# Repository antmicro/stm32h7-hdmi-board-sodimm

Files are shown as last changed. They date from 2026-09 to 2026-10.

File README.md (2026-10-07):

# SODIMM for STM32H7 HDMI Board

Copyright (c) 2026 [Antmicro](https://www.antmicro.com)

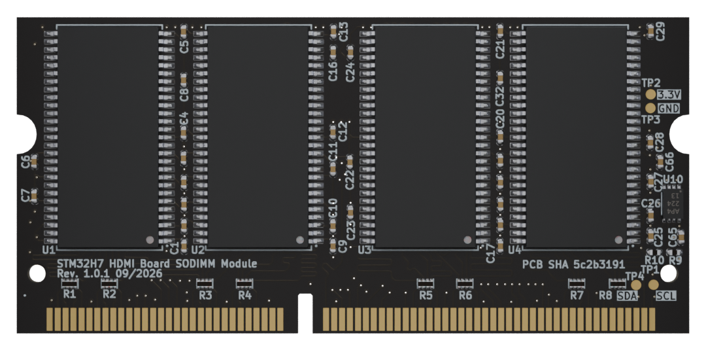
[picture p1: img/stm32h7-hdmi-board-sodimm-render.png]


## Overview

This project includes PCB design files for a custom SDRAM memory module in SO-DIMM form factor. 
This module is compatible with [STM32H7 HDMI Board](https://github.com/antmicro/stm32h7-hdmi-board) developed by Antmicro. 
It provides 512 MB of SDRAM memory supporting a maximum memory clock frequency of 200 MHz, and exposes a 32-bit data bus for full compatibility with the STM32H747 FMC (Flexible Memory Controller) used in the STM32H7 HDMI Board design. 
The board design follows the JEDEC 144-pin SODIMM pin assignment with only half of the data bus implemented (32 bits).
It also features an EEPROM memory chip for Serial Presence Detect.
The board dimensions comply with the MO-190-C SODIMM Mechanical Specifications.
The PCB design files were prepared in KiCad 10.x.

## Key features

* 512 MB of SDRAM memory
* 144 Pin SODIMM PCB edge connector
* 2Rx8 (32 data bus) memory organization
* 8 x ISSI IS42S86400F-7TL SDRAM devices with a maximum clock frequency of 200MHz
* JEDEC 144-pin SODIMM pin-assignment with only half of the data bus implemented (DQ[0..31])
* Board outline compliant with the MO-190-C SODIMM Mechanical Specifications
* Compatible with STM32H747 FMC
* 67.6 x 31.75 mm (2.66 x 1.25 inch) PCB outline

## Project structure

The main directory contains KiCad PCB project files, the LICENSE, and this README, and the img directory contains graphics for this README.

## Licensing

This project is published under the [Apache-2.0](LICENSE) license.

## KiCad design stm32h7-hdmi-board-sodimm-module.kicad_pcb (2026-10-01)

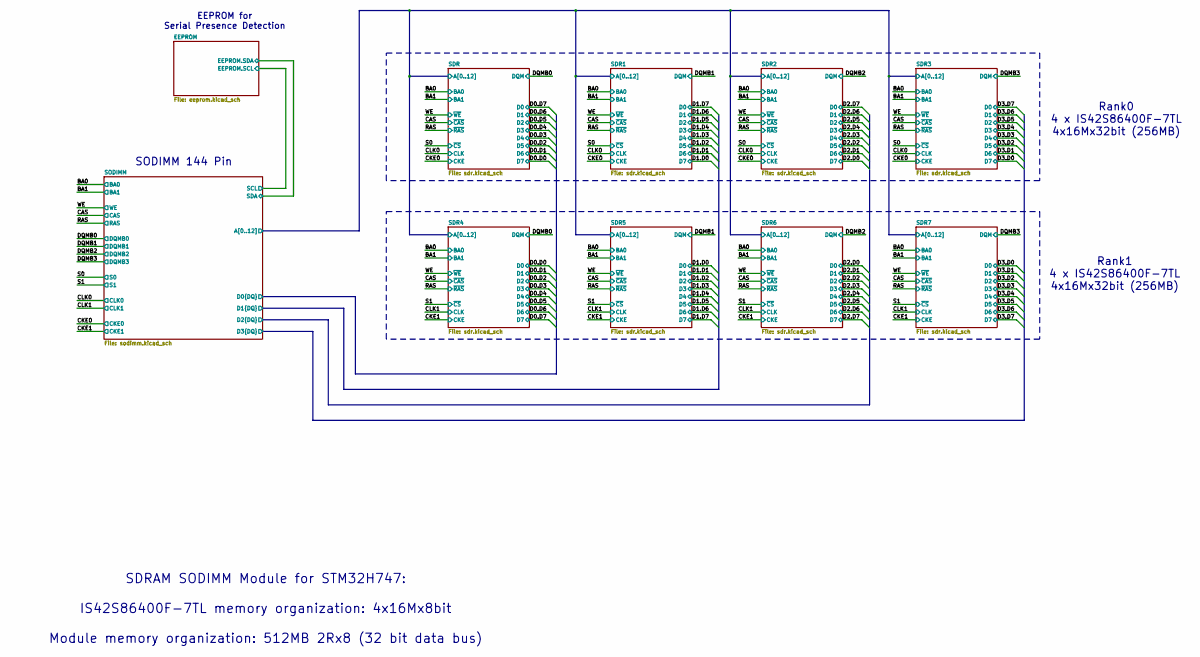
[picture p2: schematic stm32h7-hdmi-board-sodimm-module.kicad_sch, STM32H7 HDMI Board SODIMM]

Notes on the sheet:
Rank0 4 x IS42S86400F-7TL 4x16Mx32bit (256MB)
Rank1 4 x IS42S86400F-7TL 4x16Mx32bit (256MB)
SDRAM SODIMM Module for STM32H747: IS42S86400F-7TL memory organization: 4x16Mx8bit Module memory organization: 512MB 2Rx8 (32 bit data bus)
SODIMM 144 Pin
EEPROM for Serial Presence Detection

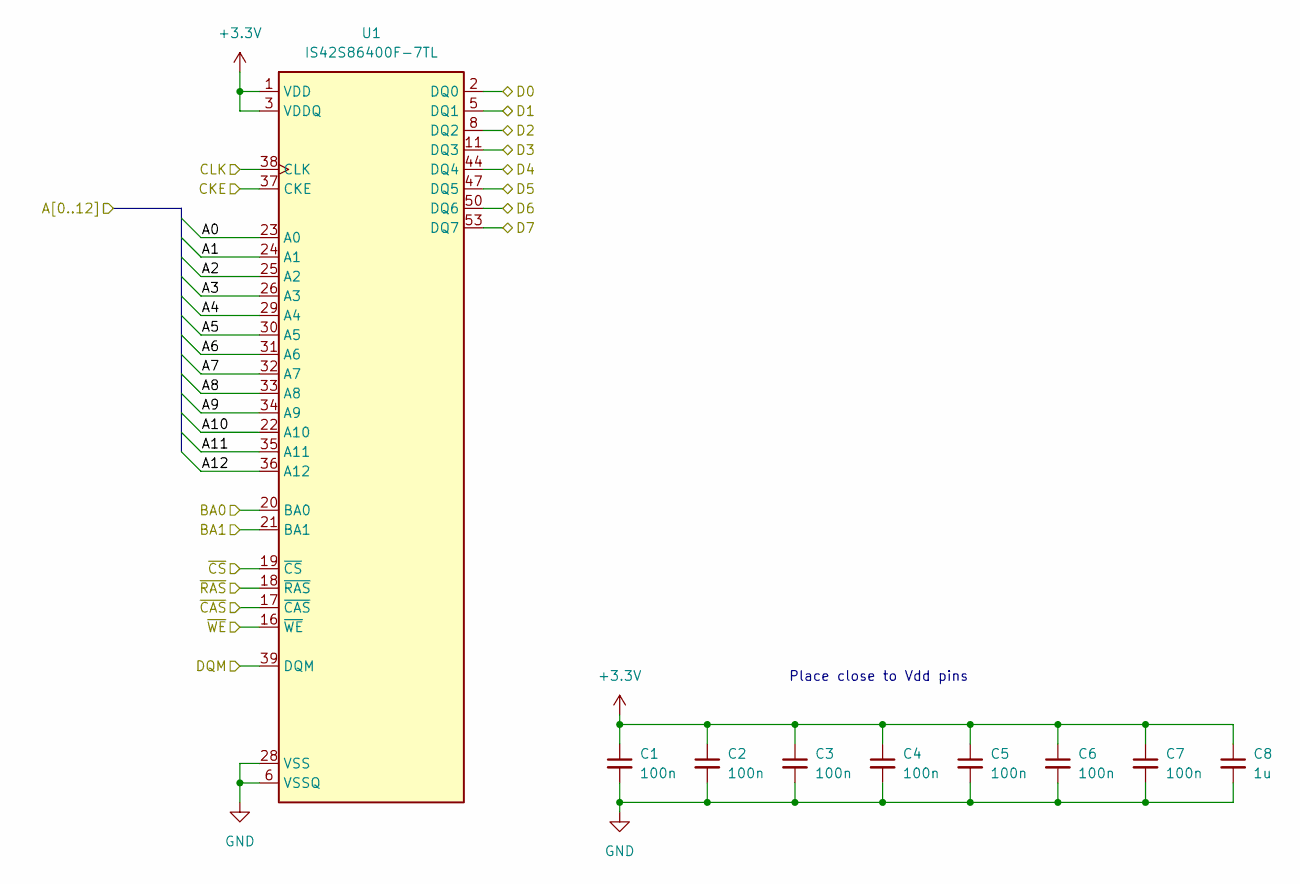
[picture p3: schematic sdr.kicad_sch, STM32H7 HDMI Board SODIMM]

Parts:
C1, C2, C3, C4, C5, C6, C7: C_100n_0402; C_0402_1005Metric; Voltage 50V; MPN GRM155R61H104KE14D
C8: C_1u_0402; C_0402_1005Metric; MPN C1005X6S1A105K050BC
U1: IS42S86400F-7TL; TSOP-II-54_22.2x10.16mm_P0.8mm; MPN IS42S86400F-7TL

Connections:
+3.3V: C1.1, C2.1, C3.1, C4.1, C5.1, C6.1, C7.1, C8.1, U1.1 (VDD), U1.3 (VDDQ), U1.9 (VDDQ), U1.14 (VDD), U1.27 (VDD), U1.43 (VDDQ), U1.49 (VDDQ); also elsewhere on the board
/BA0: U1.20 (BA0); also elsewhere on the board
/BA1: U1.21 (BA1); also elsewhere on the board
/CAS: U1.17 (~CAS); also elsewhere on the board
/CKE0: U1.37 (CKE); also elsewhere on the board
/CLK0: U1.38 (CLK); also elsewhere on the board
/DQMB0: U1.39 (DQM); also elsewhere on the board
/RAS: U1.18 (~RAS); also elsewhere on the board
/S0: U1.19 (~CS); also elsewhere on the board
/SDR/A0: U1.23 (A0); also elsewhere on the board
/SDR/A1: U1.24 (A1); also elsewhere on the board
/SDR/A2: U1.25 (A2); also elsewhere on the board
/SDR/A3: U1.26 (A3); also elsewhere on the board
/SDR/A4: U1.29 (A4); also elsewhere on the board
/SDR/A5: U1.30 (A5); also elsewhere on the board
/SDR/A6: U1.31 (A6); also elsewhere on the board
/SDR/A7: U1.32 (A7); also elsewhere on the board
/SDR/A8: U1.33 (A8); also elsewhere on the board
/SDR/A9: U1.34 (A9); also elsewhere on the board
/SDR/A10: U1.22 (A10); also elsewhere on the board
/SDR/A11: U1.35 (A11); also elsewhere on the board
/SDR/A12: U1.36 (A12); also elsewhere on the board
/SODIMM/D0.D0: U1.53 (DQ7); also elsewhere on the board
/SODIMM/D0.D1: U1.50 (DQ6); also elsewhere on the board
/SODIMM/D0.D2: U1.47 (DQ5); also elsewhere on the board
/SODIMM/D0.D3: U1.44 (DQ4); also elsewhere on the board
/SODIMM/D0.D4: U1.11 (DQ3); also elsewhere on the board
/SODIMM/D0.D5: U1.8 (DQ2); also elsewhere on the board
/SODIMM/D0.D6: U1.5 (DQ1); also elsewhere on the board
/SODIMM/D0.D7: U1.2 (DQ0); also elsewhere on the board
/WE: U1.16 (~WE); also elsewhere on the board
GND: C1.2, C2.2, C3.2, C4.2, C5.2, C6.2, C7.2, C8.2, U1.6 (VSSQ), U1.12 (VSSQ), U1.28 (VSS), U1.41 (VSS), U1.46 (VSSQ), U1.52 (VSSQ), U1.54 (VSS); also elsewhere on the board

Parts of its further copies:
C9, C10, C11, C12, C13, C14, C15, C17, C18, C19, C20, C21, C22, C23, C25, C26, C27, C28, C29, C30, C31, C33, C34, C35, C36, C37, C38, C39, C41, C42, C43, C44, C45, C46, C47, C49, C50, C51, C52, C53, C54, C55, C57, C58, C59, C60, C61, C62, C63: C_100n_0402; C_0402_1005Metric; Voltage 50V; MPN GRM155R61H104KE14D
C16, C24, C32, C40, C48, C56, C64: C_1u_0402; C_0402_1005Metric; MPN C1005X6S1A105K050BC
U2, U3, U4, U5, U6, U7, U8: IS42S86400F-7TL; TSOP-II-54_22.2x10.16mm_P0.8mm; MPN IS42S86400F-7TL

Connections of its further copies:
+3.3V: C9.1, C10.1, C11.1, C12.1, C13.1, C14.1, C15.1, C16.1, C17.1, C18.1, C19.1, C20.1, C21.1, C22.1, C23.1, C24.1, C25.1, C26.1, C27.1, C28.1, C29.1, C30.1, C31.1, C32.1, C33.1, C34.1, C35.1, C36.1, C37.1, C38.1, C39.1, C40.1, C41.1, C42.1, C43.1, C44.1, C45.1, C46.1, C47.1, C48.1, C49.1, C50.1, C51.1, C52.1, C53.1, C54.1, C55.1, C56.1, C57.1, C58.1, C59.1, C60.1, C61.1, C62.1, C63.1, C64.1, U2.1 (VDD), U2.3 (VDDQ), U2.9 (VDDQ), U2.14 (VDD), U2.27 (VDD), U2.43 (VDDQ), U2.49 (VDDQ), U3.1 (VDD), U3.3 (VDDQ), U3.9 (VDDQ), U3.14 (VDD), U3.27 (VDD), U3.43 (VDDQ), U3.49 (VDDQ), U4.1 (VDD), U4.3 (VDDQ), U4.9 (VDDQ), U4.14 (VDD), U4.27 (VDD), U4.43 (VDDQ), U4.49 (VDDQ), U5.1 (VDD), U5.3 (VDDQ), U5.9 (VDDQ), U5.14 (VDD), U5.27 (VDD), U5.43 (VDDQ), U5.49 (VDDQ), U6.1 (VDD), U6.3 (VDDQ), U6.9 (VDDQ), U6.14 (VDD), U6.27 (VDD), U6.43 (VDDQ), U6.49 (VDDQ), U7.1 (VDD), U7.3 (VDDQ), U7.9 (VDDQ), U7.14 (VDD), U7.27 (VDD), U7.43 (VDDQ), U7.49 (VDDQ), U8.1 (VDD), U8.3 (VDDQ), U8.9 (VDDQ), U8.14 (VDD), U8.27 (VDD), U8.43 (VDDQ), U8.49 (VDDQ); also elsewhere on the board
/BA0: U2.20 (BA0), U3.20 (BA0), U4.20 (BA0), U5.20 (BA0), U6.20 (BA0), U7.20 (BA0), U8.20 (BA0); also elsewhere on the board
/BA1: U2.21 (BA1), U3.21 (BA1), U4.21 (BA1), U5.21 (BA1), U6.21 (BA1), U7.21 (BA1), U8.21 (BA1); also elsewhere on the board
/CAS: U2.17 (~CAS), U3.17 (~CAS), U4.17 (~CAS), U5.17 (~CAS), U6.17 (~CAS), U7.17 (~CAS), U8.17 (~CAS); also elsewhere on the board
/CKE0: U2.37 (CKE), U3.37 (CKE), U4.37 (CKE); also elsewhere on the board
/CKE1: U5.37 (CKE), U6.37 (CKE), U7.37 (CKE), U8.37 (CKE); also elsewhere on the board
/CLK0: U2.38 (CLK), U3.38 (CLK), U4.38 (CLK); also elsewhere on the board
/CLK1: U5.38 (CLK), U6.38 (CLK), U7.38 (CLK), U8.38 (CLK); also elsewhere on the board
/DQMB0: U5.39 (DQM); also elsewhere on the board
/DQMB1: U2.39 (DQM), U6.39 (DQM); also elsewhere on the board
/DQMB2: U3.39 (DQM), U7.39 (DQM); also elsewhere on the board
/DQMB3: U4.39 (DQM), U8.39 (DQM); also elsewhere on the board
/RAS: U2.18 (~RAS), U3.18 (~RAS), U4.18 (~RAS), U5.18 (~RAS), U6.18 (~RAS), U7.18 (~RAS), U8.18 (~RAS); also elsewhere on the board
/S0: U2.19 (~CS), U3.19 (~CS), U4.19 (~CS); also elsewhere on the board
/S1: U5.19 (~CS), U6.19 (~CS), U7.19 (~CS), U8.19 (~CS); also elsewhere on the board
/SDR/A0: U2.23 (A0), U3.23 (A0), U4.23 (A0), U5.23 (A0), U6.23 (A0), U7.23 (A0), U8.23 (A0); also elsewhere on the board
/SDR/A1: U2.24 (A1), U3.24 (A1), U4.24 (A1), U5.24 (A1), U6.24 (A1), U7.24 (A1), U8.24 (A1); also elsewhere on the board
/SDR/A2: U2.25 (A2), U3.25 (A2), U4.25 (A2), U5.25 (A2), U6.25 (A2), U7.25 (A2), U8.25 (A2); also elsewhere on the board
/SDR/A3: U2.26 (A3), U3.26 (A3), U4.26 (A3), U5.26 (A3), U6.26 (A3), U7.26 (A3), U8.26 (A3); also elsewhere on the board
/SDR/A4: U2.29 (A4), U3.29 (A4), U4.29 (A4), U5.29 (A4), U6.29 (A4), U7.29 (A4), U8.29 (A4); also elsewhere on the board
/SDR/A5: U2.30 (A5), U3.30 (A5), U4.30 (A5), U5.30 (A5), U6.30 (A5), U7.30 (A5), U8.30 (A5); also elsewhere on the board
/SDR/A6: U2.31 (A6), U3.31 (A6), U4.31 (A6), U5.31 (A6), U6.31 (A6), U7.31 (A6), U8.31 (A6); also elsewhere on the board
/SDR/A7: U2.32 (A7), U3.32 (A7), U4.32 (A7), U5.32 (A7), U6.32 (A7), U7.32 (A7), U8.32 (A7); also elsewhere on the board
/SDR/A8: U2.33 (A8), U3.33 (A8), U4.33 (A8), U5.33 (A8), U6.33 (A8), U7.33 (A8), U8.33 (A8); also elsewhere on the board
/SDR/A9: U2.34 (A9), U3.34 (A9), U4.34 (A9), U5.34 (A9), U6.34 (A9), U7.34 (A9), U8.34 (A9); also elsewhere on the board
/SDR/A10: U2.22 (A10), U3.22 (A10), U4.22 (A10), U5.22 (A10), U6.22 (A10), U7.22 (A10), U8.22 (A10); also elsewhere on the board
/SDR/A11: U2.35 (A11), U3.35 (A11), U4.35 (A11), U5.35 (A11), U6.35 (A11), U7.35 (A11), U8.35 (A11); also elsewhere on the board
/SDR/A12: U2.36 (A12), U3.36 (A12), U4.36 (A12), U5.36 (A12), U6.36 (A12), U7.36 (A12), U8.36 (A12); also elsewhere on the board
/SODIMM/D0.D0: U5.2 (DQ0); also elsewhere on the board
/SODIMM/D0.D1: U5.5 (DQ1); also elsewhere on the board
/SODIMM/D0.D2: U5.8 (DQ2); also elsewhere on the board
/SODIMM/D0.D3: U5.11 (DQ3); also elsewhere on the board
/SODIMM/D0.D4: U5.44 (DQ4); also elsewhere on the board
/SODIMM/D0.D5: U5.47 (DQ5); also elsewhere on the board
/SODIMM/D0.D6: U5.50 (DQ6); also elsewhere on the board
/SODIMM/D0.D7: U5.53 (DQ7); also elsewhere on the board
/SODIMM/D1.D0: U2.53 (DQ7), U6.2 (DQ0); also elsewhere on the board
/SODIMM/D1.D1: U2.50 (DQ6), U6.5 (DQ1); also elsewhere on the board
/SODIMM/D1.D2: U2.47 (DQ5), U6.8 (DQ2); also elsewhere on the board
/SODIMM/D1.D3: U2.44 (DQ4), U6.11 (DQ3); also elsewhere on the board
/SODIMM/D1.D4: U2.11 (DQ3), U6.44 (DQ4); also elsewhere on the board
/SODIMM/D1.D5: U2.8 (DQ2), U6.47 (DQ5); also elsewhere on the board
/SODIMM/D1.D6: U2.5 (DQ1), U6.50 (DQ6); also elsewhere on the board
/SODIMM/D1.D7: U2.2 (DQ0), U6.53 (DQ7); also elsewhere on the board
/SODIMM/D2.D0: U3.53 (DQ7), U7.2 (DQ0); also elsewhere on the board
/SODIMM/D2.D1: U3.50 (DQ6), U7.5 (DQ1); also elsewhere on the board
/SODIMM/D2.D2: U3.47 (DQ5), U7.8 (DQ2); also elsewhere on the board
/SODIMM/D2.D3: U3.44 (DQ4), U7.11 (DQ3); also elsewhere on the board
/SODIMM/D2.D4: U3.11 (DQ3), U7.44 (DQ4); also elsewhere on the board
/SODIMM/D2.D5: U3.8 (DQ2), U7.47 (DQ5); also elsewhere on the board
/SODIMM/D2.D6: U3.5 (DQ1), U7.50 (DQ6); also elsewhere on the board
/SODIMM/D2.D7: U3.2 (DQ0), U7.53 (DQ7); also elsewhere on the board
/SODIMM/D3.D0: U4.53 (DQ7), U8.2 (DQ0); also elsewhere on the board
/SODIMM/D3.D1: U4.50 (DQ6), U8.5 (DQ1); also elsewhere on the board
/SODIMM/D3.D2: U4.47 (DQ5), U8.8 (DQ2); also elsewhere on the board
/SODIMM/D3.D3: U4.44 (DQ4), U8.11 (DQ3); also elsewhere on the board
/SODIMM/D3.D4: U4.11 (DQ3), U8.44 (DQ4); also elsewhere on the board
/SODIMM/D3.D5: U4.8 (DQ2), U8.47 (DQ5); also elsewhere on the board
/SODIMM/D3.D6: U4.5 (DQ1), U8.50 (DQ6); also elsewhere on the board
/SODIMM/D3.D7: U4.2 (DQ0), U8.53 (DQ7); also elsewhere on the board
/WE: U2.16 (~WE), U3.16 (~WE), U4.16 (~WE), U5.16 (~WE), U6.16 (~WE), U7.16 (~WE), U8.16 (~WE); also elsewhere on the board
GND: C9.2, C10.2, C11.2, C12.2, C13.2, C14.2, C15.2, C16.2, C17.2, C18.2, C19.2, C20.2, C21.2, C22.2, C23.2, C24.2, C25.2, C26.2, C27.2, C28.2, C29.2, C30.2, C31.2, C32.2, C33.2, C34.2, C35.2, C36.2, C37.2, C38.2, C39.2, C40.2, C41.2, C42.2, C43.2, C44.2, C45.2, C46.2, C47.2, C48.2, C49.2, C50.2, C51.2, C52.2, C53.2, C54.2, C55.2, C56.2, C57.2, C58.2, C59.2, C60.2, C61.2, C62.2, C63.2, C64.2, U2.6 (VSSQ), U2.12 (VSSQ), U2.28 (VSS), U2.41 (VSS), U2.46 (VSSQ), U2.52 (VSSQ), U2.54 (VSS), U3.6 (VSSQ), U3.12 (VSSQ), U3.28 (VSS), U3.41 (VSS), U3.46 (VSSQ), U3.52 (VSSQ), U3.54 (VSS), U4.6 (VSSQ), U4.12 (VSSQ), U4.28 (VSS), U4.41 (VSS), U4.46 (VSSQ), U4.52 (VSSQ), U4.54 (VSS), U5.6 (VSSQ), U5.12 (VSSQ), U5.28 (VSS), U5.41 (VSS), U5.46 (VSSQ), U5.52 (VSSQ), U5.54 (VSS), U6.6 (VSSQ), U6.12 (VSSQ), U6.28 (VSS), U6.41 (VSS), U6.46 (VSSQ), U6.52 (VSSQ), U6.54 (VSS), U7.6 (VSSQ), U7.12 (VSSQ), U7.28 (VSS), U7.41 (VSS), U7.46 (VSSQ), U7.52 (VSSQ), U7.54 (VSS), U8.6 (VSSQ), U8.12 (VSSQ), U8.28 (VSS), U8.41 (VSS), U8.46 (VSSQ), U8.52 (VSSQ), U8.54 (VSS); also elsewhere on the board

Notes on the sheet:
Place close to Vdd pins

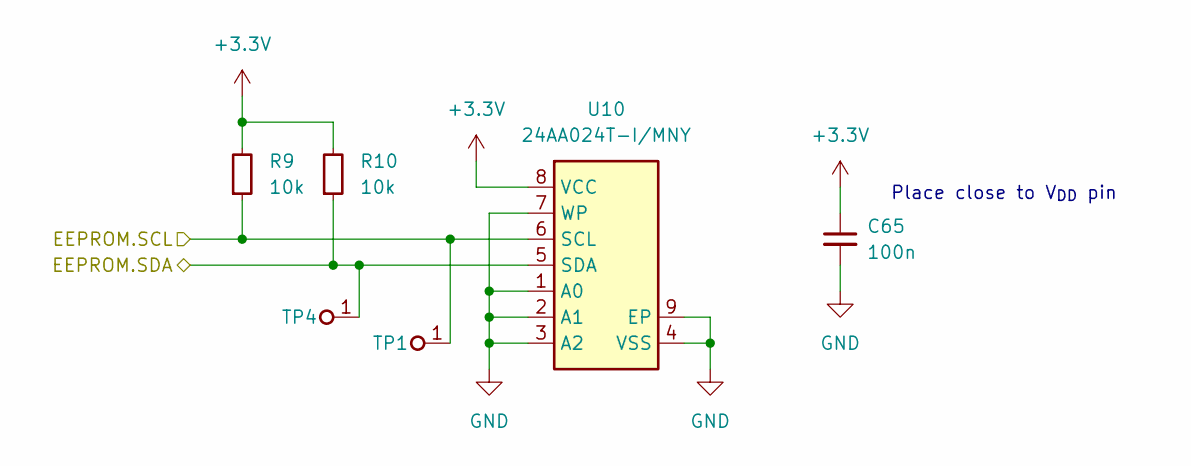
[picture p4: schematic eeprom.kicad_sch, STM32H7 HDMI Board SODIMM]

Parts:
C65: C_100n_0402; C_0402_1005Metric; Voltage 50V; MPN GRM155R61H104KE14D
R9, R10: R_10k_0402; R_0402_1005Metric; Tolerance 1%; MPN CR0402-FX-1002GLF
TP1, TP4: TP_1mm_SMD; TP_SMD_1mm
U10: 24AA024_TDFN; TDFN-8-1EP_2x3x0.8mm_P0.5mm_EP1.3x1.4mm; MPN 24AA024T-I/MNY

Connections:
+3.3V: C65.1, R9.2, R10.2, U10.8 (VCC); also elsewhere on the board
/EEPROM/EEPROM.SCL: R9.1, TP1.1 (1_1), U10.6 (SCL); also elsewhere on the board
/EEPROM/EEPROM.SDA: R10.1, TP4.1 (1_1), U10.5 (SDA); also elsewhere on the board
GND: C65.2, U10.1 (A0), U10.2 (A1), U10.3 (A2), U10.4 (VSS), U10.7 (WP), U10.9 (EP); also elsewhere on the board

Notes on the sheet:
Place close to V_{DD} pin

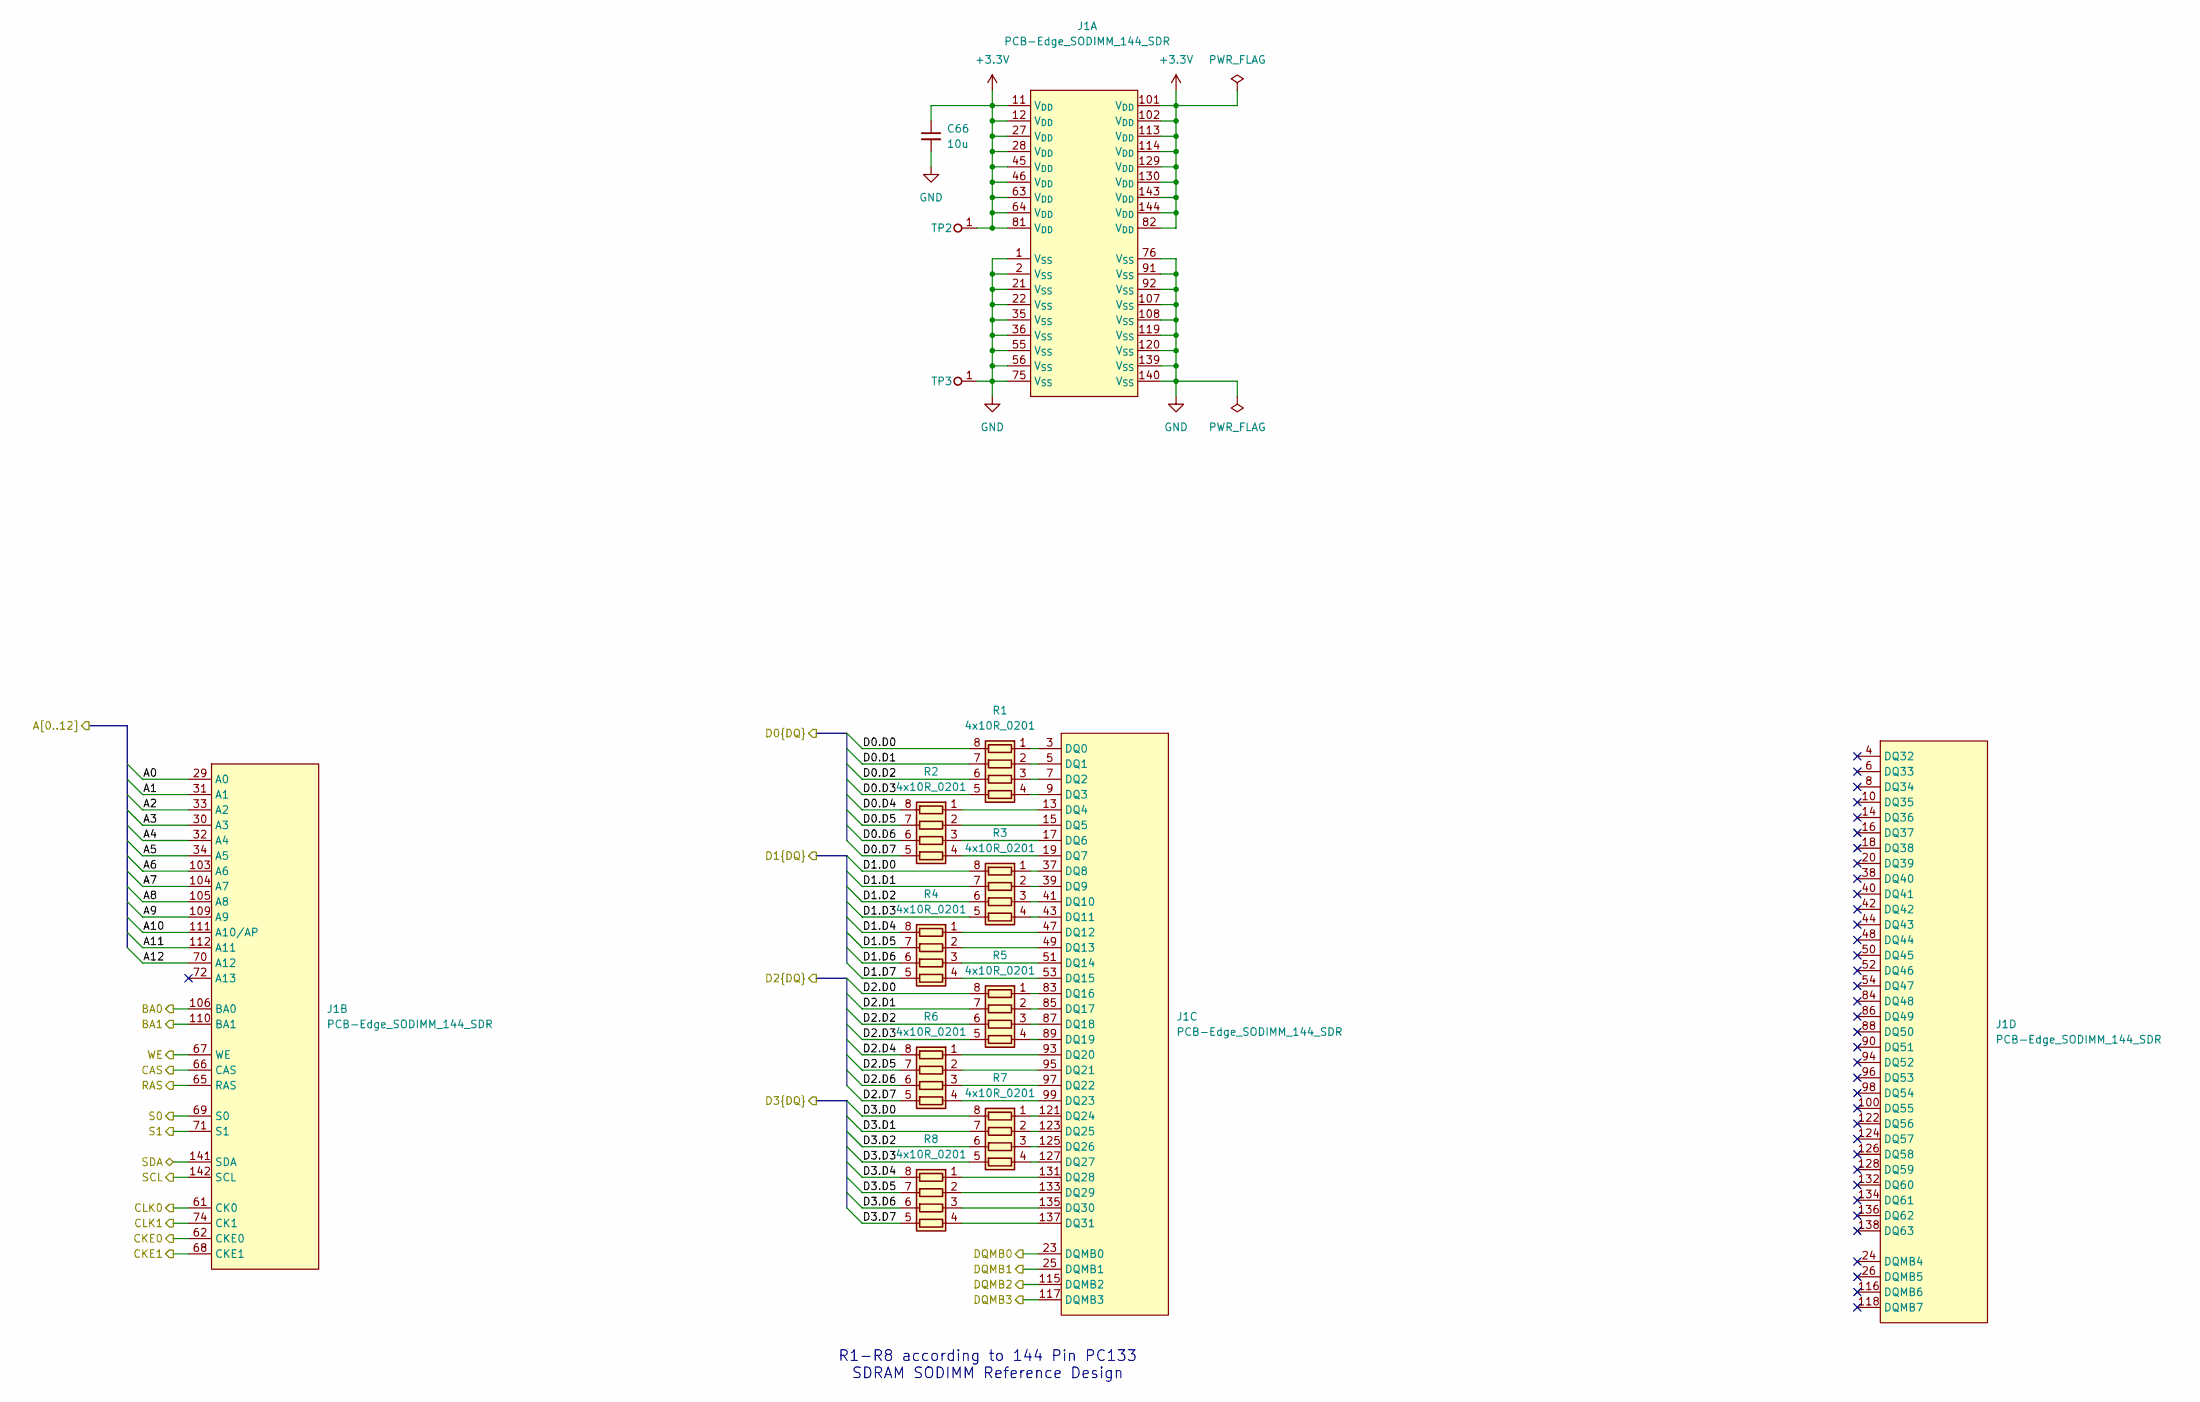
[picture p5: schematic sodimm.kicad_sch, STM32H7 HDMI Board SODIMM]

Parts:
C66: C_10u_0402; C_0402_1005Metric; MPN CC0402MRX5R5BB106
J1: PCB-Edge_SODIMM_144_SDR
R1, R2, R3, R4, R5, R6, R7, R8: 4x10R_0201_array; R_Array_4x0201_Panasonic_EXB18V; MPN EXB-18V100JX
TP2, TP3: TP_1mm_SMD; TP_SMD_1mm

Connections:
+3.3V: C66.1, J1.11 (V_{DD}), J1.12 (V_{DD}), J1.27 (V_{DD}), J1.28 (V_{DD}), J1.45 (V_{DD}), J1.46 (V_{DD}), J1.63 (V_{DD}), J1.64 (V_{DD}), J1.81 (V_{DD}), J1.82 (V_{DD}), J1.101 (V_{DD}), J1.102 (V_{DD}), J1.113 (V_{DD}), J1.114 (V_{DD}), J1.129 (V_{DD}), J1.130 (V_{DD}), J1.143 (V_{DD}), J1.144 (V_{DD}), TP2.1 (1_1); also elsewhere on the board
/BA0: J1.106 (BA0); also elsewhere on the board
/BA1: J1.110 (BA1); also elsewhere on the board
/CAS: J1.66 (CAS); also elsewhere on the board
/CKE0: J1.62 (CKE0); also elsewhere on the board
/CKE1: J1.68 (CKE1); also elsewhere on the board
/CLK0: J1.61 (CK0); also elsewhere on the board
/CLK1: J1.74 (CK1); also elsewhere on the board
/DQMB0: J1.23 (DQMB0); also elsewhere on the board
/DQMB1: J1.25 (DQMB1); also elsewhere on the board
/DQMB2: J1.115 (DQMB2); also elsewhere on the board
/DQMB3: J1.117 (DQMB3); also elsewhere on the board
/EEPROM/EEPROM.SCL: J1.142 (SCL); also elsewhere on the board
/EEPROM/EEPROM.SDA: J1.141 (SDA); also elsewhere on the board
/RAS: J1.65 (RAS); also elsewhere on the board
/S0: J1.69 (S0); also elsewhere on the board
/S1: J1.71 (S1); also elsewhere on the board
/SDR/A0: J1.29 (A0); also elsewhere on the board
/SDR/A1: J1.31 (A1); also elsewhere on the board
/SDR/A2: J1.33 (A2); also elsewhere on the board
/SDR/A3: J1.30 (A3); also elsewhere on the board
/SDR/A4: J1.32 (A4); also elsewhere on the board
/SDR/A5: J1.34 (A5); also elsewhere on the board
/SDR/A6: J1.103 (A6); also elsewhere on the board
/SDR/A7: J1.104 (A7); also elsewhere on the board
/SDR/A8: J1.105 (A8); also elsewhere on the board
/SDR/A9: J1.109 (A9); also elsewhere on the board
/SDR/A10: J1.111 (A10/AP); also elsewhere on the board
/SDR/A11: J1.112 (A11); also elsewhere on the board
/SDR/A12: J1.70 (A12); also elsewhere on the board
/SODIMM/D0.D0: R1.8 (R1.2); also elsewhere on the board
/SODIMM/D0.D1: R1.7 (R2.2); also elsewhere on the board
/SODIMM/D0.D2: R1.6 (R3.2); also elsewhere on the board
/SODIMM/D0.D3: R1.5 (R4.2); also elsewhere on the board
/SODIMM/D0.D4: R2.8 (R1.2); also elsewhere on the board
/SODIMM/D0.D5: R2.7 (R2.2); also elsewhere on the board
/SODIMM/D0.D6: R2.6 (R3.2); also elsewhere on the board
/SODIMM/D0.D7: R2.5 (R4.2); also elsewhere on the board
/SODIMM/D1.D0: R3.8 (R1.2); also elsewhere on the board
/SODIMM/D1.D1: R3.7 (R2.2); also elsewhere on the board
/SODIMM/D1.D2: R3.6 (R3.2); also elsewhere on the board
/SODIMM/D1.D3: R3.5 (R4.2); also elsewhere on the board
/SODIMM/D1.D4: R4.8 (R1.2); also elsewhere on the board
/SODIMM/D1.D5: R4.7 (R2.2); also elsewhere on the board
/SODIMM/D1.D6: R4.6 (R3.2); also elsewhere on the board
/SODIMM/D1.D7: R4.5 (R4.2); also elsewhere on the board
/SODIMM/D2.D0: R5.8 (R1.2); also elsewhere on the board
/SODIMM/D2.D1: R5.7 (R2.2); also elsewhere on the board
/SODIMM/D2.D2: R5.6 (R3.2); also elsewhere on the board
/SODIMM/D2.D3: R5.5 (R4.2); also elsewhere on the board
/SODIMM/D2.D4: R6.8 (R1.2); also elsewhere on the board
/SODIMM/D2.D5: R6.7 (R2.2); also elsewhere on the board
/SODIMM/D2.D6: R6.6 (R3.2); also elsewhere on the board
/SODIMM/D2.D7: R6.5 (R4.2); also elsewhere on the board
/SODIMM/D3.D0: R7.8 (R1.2); also elsewhere on the board
/SODIMM/D3.D1: R7.7 (R2.2); also elsewhere on the board
/SODIMM/D3.D2: R7.6 (R3.2); also elsewhere on the board
/SODIMM/D3.D3: R7.5 (R4.2); also elsewhere on the board
/SODIMM/D3.D4: R8.8 (R1.2); also elsewhere on the board
/SODIMM/D3.D5: R8.7 (R2.2); also elsewhere on the board
/SODIMM/D3.D6: R8.6 (R3.2); also elsewhere on the board
/SODIMM/D3.D7: R8.5 (R4.2); also elsewhere on the board
/WE: J1.67 (WE); also elsewhere on the board
GND: C66.2, J1.1 (V_{SS}), J1.2 (V_{SS}), J1.21 (V_{SS}), J1.22 (V_{SS}), J1.35 (V_{SS}), J1.36 (V_{SS}), J1.55 (V_{SS}), J1.56 (V_{SS}), J1.75 (V_{SS}), J1.76 (V_{SS}), J1.91 (V_{SS}), J1.92 (V_{SS}), J1.107 (V_{SS}), J1.108 (V_{SS}), J1.119 (V_{SS}), J1.120 (V_{SS}), J1.139 (V_{SS}), J1.140 (V_{SS}), TP3.1 (1_1); also elsewhere on the board
unnamed: J1.3 (DQ0), R1.1 (R1.1)
unnamed: J1.5 (DQ1), R1.2 (R2.1)
unnamed: J1.7 (DQ2), R1.3 (R3.1)
unnamed: J1.9 (DQ3), R1.4 (R4.1)
unnamed: J1.13 (DQ4), R2.1 (R1.1)
unnamed: J1.15 (DQ5), R2.2 (R2.1)
unnamed: J1.17 (DQ6), R2.3 (R3.1)
unnamed: J1.19 (DQ7), R2.4 (R4.1)
unnamed: J1.37 (DQ8), R3.1 (R1.1)
unnamed: J1.39 (DQ9), R3.2 (R2.1)
unnamed: J1.41 (DQ10), R3.3 (R3.1)
unnamed: J1.43 (DQ11), R3.4 (R4.1)
unnamed: J1.47 (DQ12), R4.1 (R1.1)
unnamed: J1.49 (DQ13), R4.2 (R2.1)
unnamed: J1.51 (DQ14), R4.3 (R3.1)
unnamed: J1.53 (DQ15), R4.4 (R4.1)
unnamed: J1.83 (DQ16), R5.1 (R1.1)
unnamed: J1.85 (DQ17), R5.2 (R2.1)
unnamed: J1.87 (DQ18), R5.3 (R3.1)
unnamed: J1.89 (DQ19), R5.4 (R4.1)
unnamed: J1.93 (DQ20), R6.1 (R1.1)
unnamed: J1.95 (DQ21), R6.2 (R2.1)
unnamed: J1.97 (DQ22), R6.3 (R3.1)
unnamed: J1.99 (DQ23), R6.4 (R4.1)
unnamed: J1.121 (DQ24), R7.1 (R1.1)
unnamed: J1.123 (DQ25), R7.2 (R2.1)
unnamed: J1.125 (DQ26), R7.3 (R3.1)
unnamed: J1.127 (DQ27), R7.4 (R4.1)
unnamed: J1.131 (DQ28), R8.1 (R1.1)
unnamed: J1.133 (DQ29), R8.2 (R2.1)
unnamed: J1.135 (DQ30), R8.3 (R3.1)
unnamed: J1.137 (DQ31), R8.4 (R4.1)

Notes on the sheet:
R1-R8 according to 144 Pin PC133 SDRAM SODIMM Reference Design

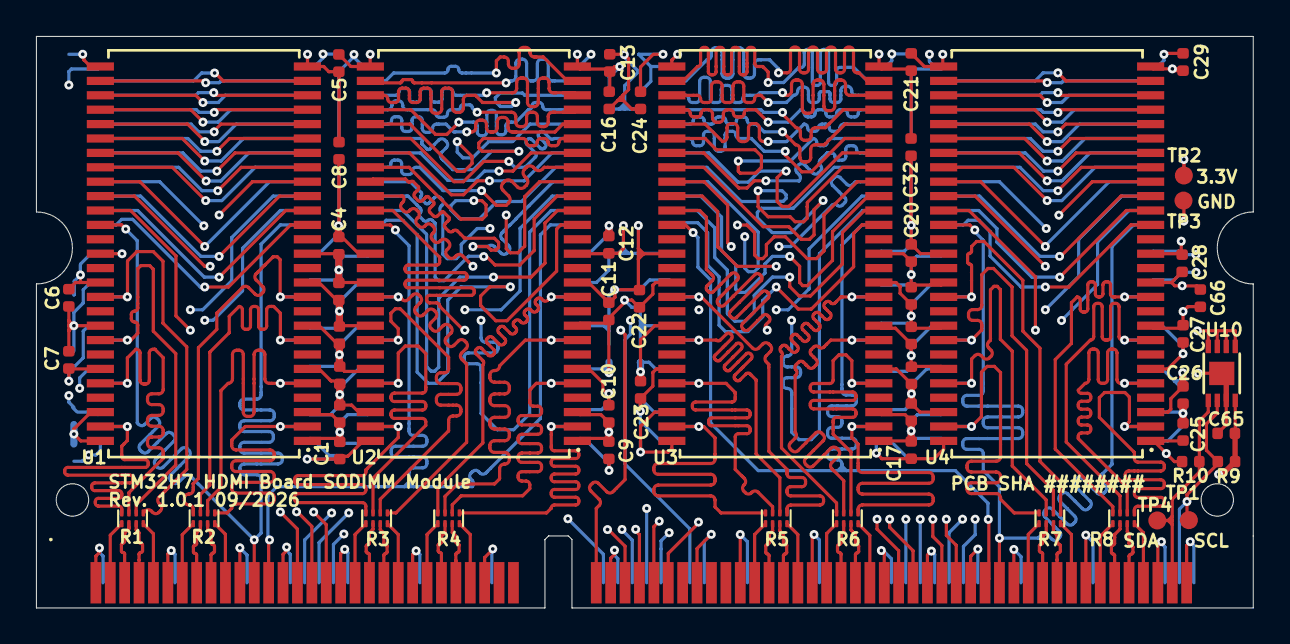
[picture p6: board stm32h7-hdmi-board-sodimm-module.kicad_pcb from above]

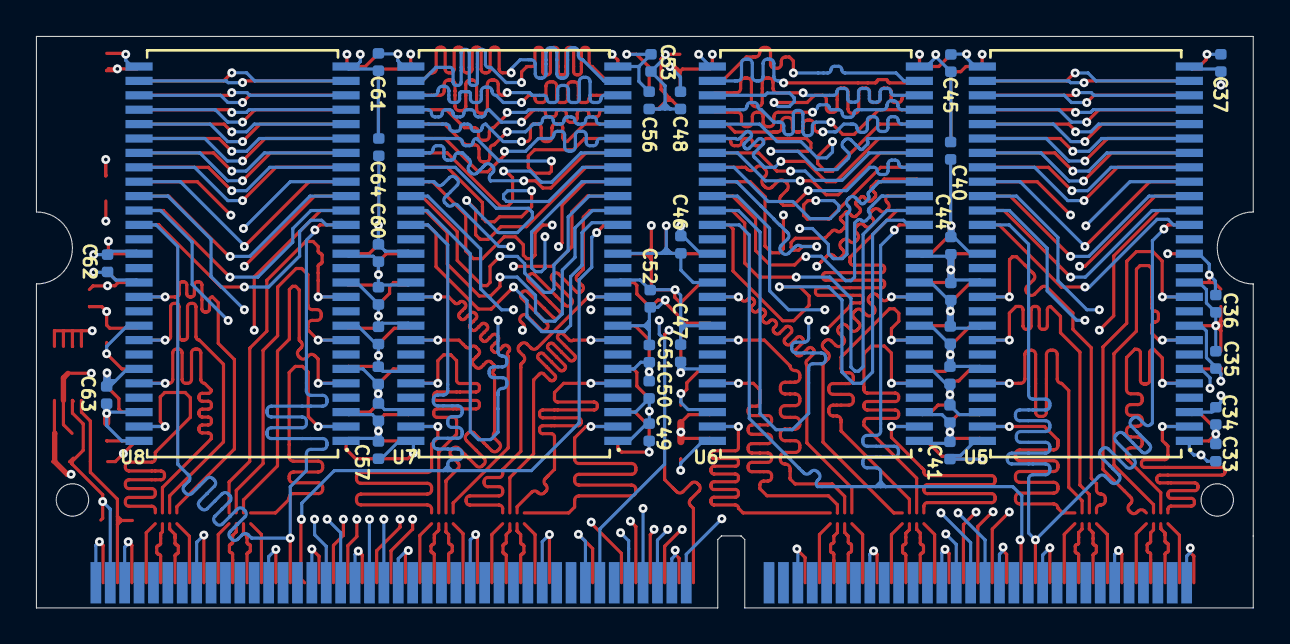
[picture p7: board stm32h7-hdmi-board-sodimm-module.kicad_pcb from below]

Board: 6 copper layers, 67.6 x 31.8 mm, 90 parts (36 on the bottom side), 96 nets.

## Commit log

2026-07-08 [#100342] Add KiCad project
    [sdr-bank-1.kicad_sch, sodimm.kicad_sch, stm32h7-hdmi-board-sodimm-module-hw.kicad_pcb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]
2026-07-08 [#100470] Add SODIMM connector to schematic
    [sodimm.kicad_sch]
2026-07-09 [#100470] Connect SODIMM to SDRAM banks
    [sdr-bank-1.kicad_sch, sodimm.kicad_sch, stm32h7-hdmi-board-sodimm-module-hw.kicad_sch]
2026-07-10 [#100470] Update SODIMM 144 pin connector
    [sodimm.kicad_sch]
2026-07-10 [#100470] Add 1u decoupling capacitors to schematic
    [sdr-bank-1.kicad_sch, sodimm.kicad_sch, stm32h7-hdmi-board-sodimm-module-hw.kicad_sch]
2026-07-10 [#100470] Switch to R in packs, assign footprints
    [sdr-bank-1.kicad_sch, stm32h7-hdmi-board-sodimm-module-hw.kicad_sch]
2026-07-10 [#100650] update pcb layout
    [stm32h7-hdmi-board-sodimm-module-hw.kicad_pcb]
2026-07-10 [#100650] Add power filled zones
    [stm32h7-hdmi-board-sodimm-module-hw.kicad_pcb]
2026-07-13 [#100650] Add user layers
    [stm32h7-hdmi-board-sodimm-module-hw.kicad_pcb]
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2026-07-13 [#100650] PCB layout update - placing ICs
    [sodimm.kicad_sch, stm32h7-hdmi-board-sodimm-module-hw.kicad_pcb, stm32h7-hdmi-board-sodimm-module-hw.kicad_sch]
2026-07-13 [#100470] Change schematic hierarchy
    [sdr-bank-1.kicad_sch, sdr.kicad_sch, sodimm.kicad_sch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]
2026-07-13 [#100650] Swap R packs footprints
    [stm32h7-hdmi-board-sodimm-module-hw.kicad_pcb]
2026-09-21 [#100650] Add Net Classes for impedance controlled signals
    [stm32h7-hdmi-board-sodimm-module-hw.kicad_pcb]
2026-09-21 [#100650] PCB layout update
    [stm32h7-hdmi-board-sodimm-module-hw.kicad_pcb]
2026-09-21 [#100650] Add Antmicro logo
    [sodimm.kicad_sch, stm32h7-hdmi-board-sodimm-module-hw.kicad_pcb, stm32h7-hdmi-board-sodimm-module-hw.kicad_sch]
2026-09-21 [#100650] Add rev number
    [sdr.kicad_sch, stm32h7-hdmi-board-sodimm-module-hw.kicad_pcb]
2026-09-21 [#100470] Add signals to Net Classes
    [sodimm.kicad_sch, stm32h7-hdmi-board-sodimm-module-hw.kicad_sch]
2026-09-21 [#100650] Add EEPROM memory IC for Serial Presence Detection
    [eeprom.kicad_sch, sdr.kicad_sch, sodimm.kicad_sch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]
2026-09-21 [#100650] Change EEPROM memory IC
    [eeprom.kicad_sch, stm32h7-hdmi-board-sodimm-module-hw.kicad_pcb, stm32h7-hdmi-board-sodimm-module-hw.kicad_sch]
2026-09-21 [#100650] Update schematic labels, add bulk cap
    [eeprom.kicad_sch, sdr.kicad_sch, sodimm.kicad_sch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]
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2026-09-21 [#100919] Route data bus
    [sdr.kicad_sch, sodimm.kicad_sch, stm32h7-hdmi-board-sodimm-module-hw.kicad_pcb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]
2026-09-21 [#100919] Reroute data bus, route clk0 and clk1
    [stm32h7-hdmi-board-sodimm-module-hw.kicad_pcb, stm32h7-hdmi-board-sodimm-module-hw.kicad_sch]
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2026-09-21 [#100919] Rerouting clock, routing ADDR bus
    [stm32h7-hdmi-board-sodimm-module-hw.kicad_pcb]
2026-09-21 [#100919] Routing ADDR bus
    [stm32h7-hdmi-board-sodimm-module-hw.kicad_pcb]
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2026-09-21 [#100919] Routig EEPROM memory
    [stm32h7-hdmi-board-sodimm-module-hw.kicad_pcb]
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2026-09-21 [#100919] Add test points
    [eeprom.kicad_sch, sodimm.kicad_sch, stm32h7-hdmi-board-sodimm-module-hw.kicad_pcb]
2026-09-21 [#101386] Matching [sodimm <-> R packs] tracks
    [stm32h7-hdmi-board-sodimm-module-hw.kicad_pcb]
2026-09-21 [#101386] Matching [R packs <-> SDRAM] tracks
    [stm32h7-hdmi-board-sodimm-module-hw.kicad_pcb]
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2026-09-21 [#101386] Matching ADDR bus
    [stm32h7-hdmi-board-sodimm-module-hw.kicad_pcb]
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2026-09-21 [#101386] Add drc exclusions
    [sodimm.kicad_sch, stm32h7-hdmi-board-sodimm-module-hw.kicad_pcb]
2026-09-21 [#101386] Change copper thickness in pcb stackup
    [stm32h7-hdmi-board-sodimm-module-hw.kicad_pcb]
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2026-09-21 [#101386] Remove logo from schematic
    [stm32h7-hdmi-board-sodimm-module-hw.kicad_sch]
2026-09-21 [#101386] Align PCB to grid
    [stm32h7-hdmi-board-sodimm-module-hw.kicad_pcb]
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2026-09-21 [#101653] Add edge connector beveling information and stackup table to mechanical layer
    [stm32h7-hdmi-board-sodimm-module-hw.kicad_pcb]
2026-09-21 [#101653] Change tracks width for internal layers
    [stm32h7-hdmi-board-sodimm-module-hw.kicad_pcb]
2026-09-21 [#101653] Add DRC custom rules for net classes
    [stm32h7-hdmi-board-sodimm-module-hw.kicad_pcb]
2026-09-21 [#101653] Change labels on schematic
    [sodimm.kicad_sch]
2026-09-21 [#101653] Unsqueeze tracks on inner layers
    [stm32h7-hdmi-board-sodimm-module-hw.kicad_pcb]
2026-09-21 [#101653] A7-A12 length matching
    [stm32h7-hdmi-board-sodimm-module-hw.kicad_pcb]
2026-09-21 [#101653] A4-A6 length matching
    [stm32h7-hdmi-board-sodimm-module-hw.kicad_pcb]
2026-09-21 [#101653] A0-A3 length matching
    [stm32h7-hdmi-board-sodimm-module-hw.kicad_pcb]
2026-09-21 [#101653] CKE length matching
    [stm32h7-hdmi-board-sodimm-module-hw.kicad_pcb]
2026-09-21 [#101653] BA length matching
    [stm32h7-hdmi-board-sodimm-module-hw.kicad_pcb]
2026-09-21 [#101653] S length matching
    [stm32h7-hdmi-board-sodimm-module-hw.kicad_pcb]
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2026-09-21 [#101653] Update DRC rules for default net class
    [stm32h7-hdmi-board-sodimm-module-hw.kicad_pcb]
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

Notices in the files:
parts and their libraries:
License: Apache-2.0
